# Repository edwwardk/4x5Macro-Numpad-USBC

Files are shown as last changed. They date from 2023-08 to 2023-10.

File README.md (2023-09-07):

## 4x5Macro-Numpad-USBC
This fork of tobychui's 4x5Macro-Numpad modifies the original design to use usbc instead of microusb as well as using a through hole reinforced port for a stronger hold on the board. Additionally, it also moves the user led to the front of the board and adds a button for resetting the mcu. Pins are identical to the 4x5Macro-Numpad to allow for using the same firmwares.

## v1.0 Known Issues
- resistor/capacitor/led designators/value missing from silkscreen in gerbers
- switch indices missing from silkscreen in gerbers
- size is larger than 100x100mm which causes upcharge (at least from jlcpcb)

### Bill of materials
(LCSC manufacturer part numbers in brackets)
- 1x CH552G (CH552G)
- 1x USBC (GT-USB-7010ASV)
- 20x switches for 4x5 layout, 17x switches for numpad layout
- 2x 0.1u 0805 capacitors (0805B104J250CT)
- 2x 0805 LEDs (17-215SURC/S530-A3/4T and BL-HJC35A-AV-TRB)
- 8x 10k 0805 resistors (SCR0805F10K)
- 2x 5.1k 0805 resistors (CR0805J80512G)
- 2x smd momentary buttons (TS5216A 250gf 025)

### Fabrication instructions
- in the "4x5Macro-Numpad-USBC/fabrication" folder there is a zip file called fabrication.zip. these are the set of gerbers required to order from JLCPCB and should work as is.

### Build Instruction

1. Send the PCB to print (See /PCB)

2. Purchase all the required materials (See BOM list)

3. 3D print the base plate (See /3D Model)

4. Install the required Arduino library for CH552G and drivers

5. Visit [4-key Macropad | imuslab](https://tobychui.github.io/4xMacropad/) (4xMacropad only) or modify the sketch in /firmware folder

6. Flash the CH552G with the sketch

### Program Flashing Instructions

As all the keyboard designs share the same MCU and programming button design, this instruction should be suitable for all the macropads / numpad in this repo.

1. Hold and press the PROG button on the PCB

2. While the button has been held, insert the USB cable into the mini USB port

3. Release the button when the Arduino code has finished compiling and ready to upload (Timing is important)

4. Wait for the upload to complete

### License

Software: MIT License

Hardware: CC BY-NC-SA

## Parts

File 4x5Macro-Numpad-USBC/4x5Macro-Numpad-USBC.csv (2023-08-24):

Source: | C:\Users\eddyk\projects\4x5Macro-Numpad-USBC\4x5Macro-Numpad-USBC\4x5Macro-Numpad-USBC.kicad_sch
Date: | 2023-08-22 8:45:27 PM
Tool: | Eeschema 7.0.2
Generator: | C:\Program Files\KiCad\7.0\bin\scripting\plugins/bom_csv_grouped_by_value.py
Component Count: | 41
Collated Components:
Item | Qty | Reference(s) | Value | LibPart | Footprint | Datasheet | DNP
1 | 2 | C1, C2 | 0.1u | Device:C_Small | Capacitor_SMD:C_0805_2012Metric_Pad1.18x1.45mm_HandSolder | ~
2 | 1 | D1 | RED | Device:LED | Capacitor_SMD:C_0805_2012Metric_Pad1.18x1.45mm_HandSolder | ~
3 | 1 | D2 | BLUE | Device:LED | Capacitor_SMD:C_0805_2012Metric_Pad1.18x1.45mm_HandSolder | ~
4 | 1 | J1 | USB-C | Connector:USB_C_Receptacle_USB2.0 | Connector_USB:USB_C_Receptacle_G-Switch_GT-USB-7010ASV | https://www.usb.org/sites/default/files/documents/usb_type-c.zip
5 | 8 | R1, R4, R5, R6, R7, R8, R9, R10 | 10k | Device:R_Small_US | Resistor_SMD:R_0805_2012Metric_Pad1.20x1.40mm_HandSolder | ~
6 | 2 | R2, R3 | 5.1k | Device:R_Small_US | Resistor_SMD:R_0805_2012Metric_Pad1.20x1.40mm_HandSolder | ~
7 | 1 | SW1 | PROG | Switch:SW_Push | custom:SW_SPST_TS5216A | ~
8 | 1 | SW2 | RESET | Switch:SW_Push | custom:SW_SPST_TS5216A | ~
9 | 1 | SW3 | [4,0] | Switch:SW_Push | Button_Switch_Keyboard:SW_Cherry_MX_1.00u_Plate | ~
10 | 1 | SW4 | [4,1] | Switch:SW_Push | Button_Switch_Keyboard:SW_Cherry_MX_1.00u_Plate | ~
11 | 1 | SW5 | [4,2] | Switch:SW_Push | Button_Switch_Keyboard:SW_Cherry_MX_1.00u_Plate | ~
12 | 1 | SW6 | [4,3] | Switch:SW_Push | Button_Switch_Keyboard:SW_Cherry_MX_1.00u_Plate | ~
13 | 2 | SW7, SW11 | [3,3] | Switch:SW_Push | Button_Switch_Keyboard:SW_Cherry_MX_1.00u_Plate | ~
14 | 1 | SW8 | [3,0] | Switch:SW_Push | Button_Switch_Keyboard:SW_Cherry_MX_1.00u_Plate | ~
15 | 1 | SW9 | [3,1] | Switch:SW_Push | Button_Switch_Keyboard:SW_Cherry_MX_1.00u_Plate | ~
16 | 1 | SW10 | [3,2] | Switch:SW_Push | Button_Switch_Keyboard:SW_Cherry_MX_1.00u_Plate | ~
17 | 1 | SW12 | [2,0] | Switch:SW_Push | Button_Switch_Keyboard:SW_Cherry_MX_1.00u_Plate | ~
18 | 1 | SW13 | [2,1] | Switch:SW_Push | Button_Switch_Keyboard:SW_Cherry_MX_1.00u_Plate | ~
19 | 1 | SW14 | [2,2] | Switch:SW_Push | Button_Switch_Keyboard:SW_Cherry_MX_1.00u_Plate | ~
20 | 1 | SW15 | [2,3] | Switch:SW_Push | Button_Switch_Keyboard:SW_Cherry_MX_1.00u_Plate | ~
21 | 2 | SW16, SW20 | [1,3] | Switch:SW_Push | Button_Switch_Keyboard:SW_Cherry_MX_1.00u_Plate | ~
22 | 1 | SW17 | [1,0] | Switch:SW_Push | Button_Switch_Keyboard:SW_Cherry_MX_1.00u_Plate | ~
23 | 1 | SW18 | [1,1] | Switch:SW_Push | Button_Switch_Keyboard:SW_Cherry_MX_1.00u_Plate | ~
24 | 1 | SW19 | [1,2] | Switch:SW_Push | Button_Switch_Keyboard:SW_Cherry_MX_1.00u_Plate | ~
25 | 2 | SW21, SW25 | [0,0] | Switch:SW_Push | Button_Switch_Keyboard:SW_Cherry_MX_1.00u_Plate | ~
26 | 1 | SW22 | [0,1] | Switch:SW_Push | Button_Switch_Keyboard:SW_Cherry_MX_1.00u_Plate | ~
27 | 1 | SW23 | [0,2] | Switch:SW_Push | Button_Switch_Keyboard:SW_Cherry_MX_1.00u_Plate | ~
28 | 1 | SW24 | [0,3] | Switch:SW_Push | Button_Switch_Keyboard:SW_Cherry_MX_1.00u_Plate | ~
29 | 1 | U1 | ~ | custom:CH552G | Package_SO:SOP-16_3.9x9.9mm_P1.27mm

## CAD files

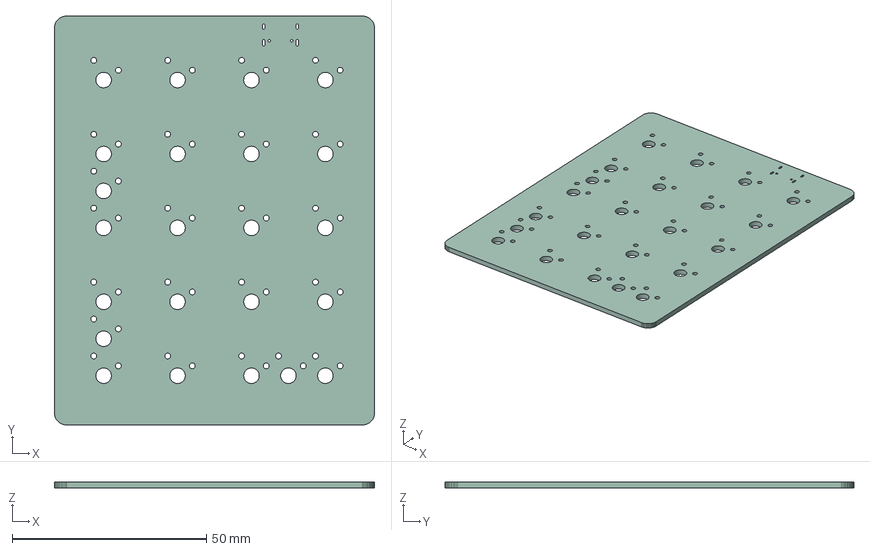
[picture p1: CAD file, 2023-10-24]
4x5Macro-Numpad-USBC/4x5Macro-Numpad-USBC.step
82.5 x 105.4 x 1.58 mm

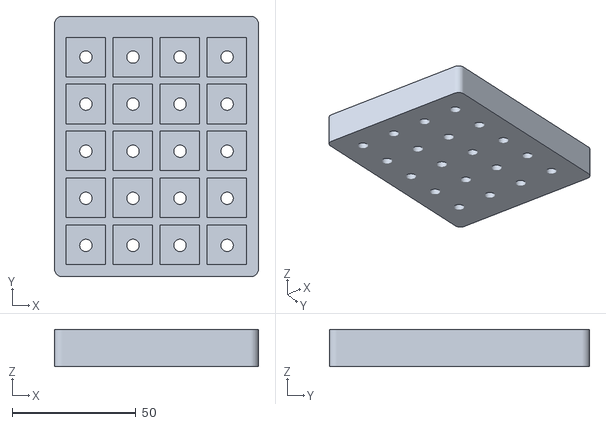
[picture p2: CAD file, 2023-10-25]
4x5Macro-Numpad-USBC/fabrication/macropad-layout-switch-jig.stl
82.5 x 105.4 x 15.0

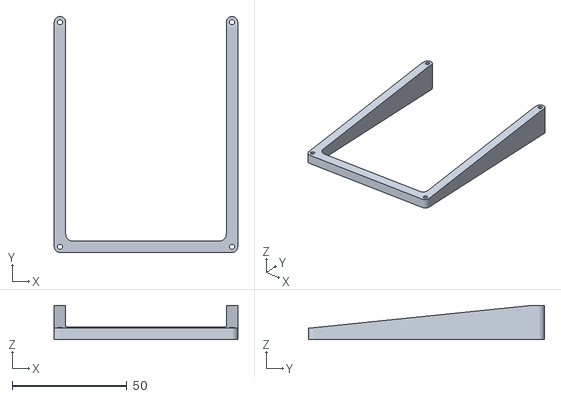
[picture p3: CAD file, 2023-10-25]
4x5Macro-Numpad-USBC/fabrication/thin-base-2.stl
79.9 x 102.8 x 15.0

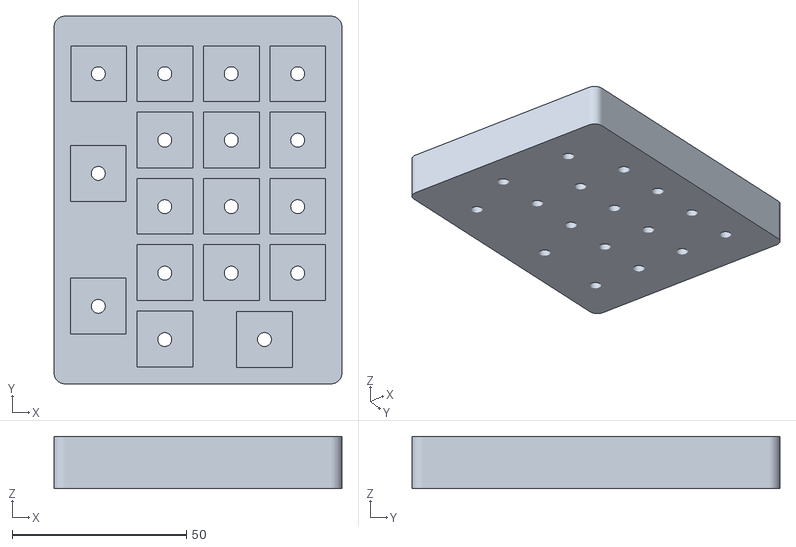
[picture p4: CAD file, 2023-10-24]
4x5Macro-Numpad-USBC/fabrication/numpad-layout-switch-jig.stl
82.5 x 105.4 x 15.0

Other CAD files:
4x5Macro-Numpad-USBC/fabrication/thin-base-1.stl

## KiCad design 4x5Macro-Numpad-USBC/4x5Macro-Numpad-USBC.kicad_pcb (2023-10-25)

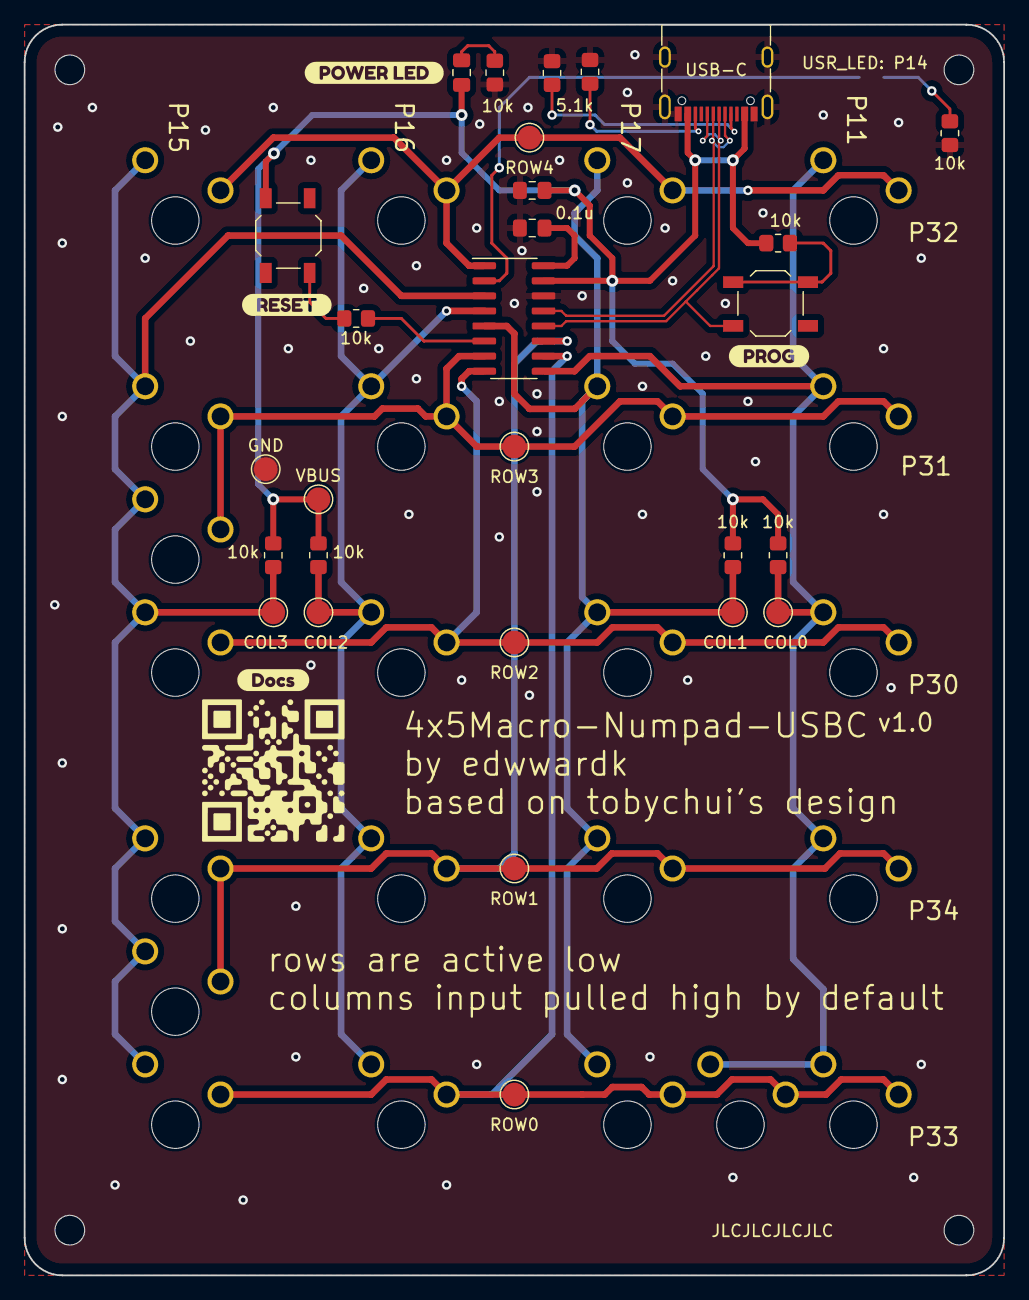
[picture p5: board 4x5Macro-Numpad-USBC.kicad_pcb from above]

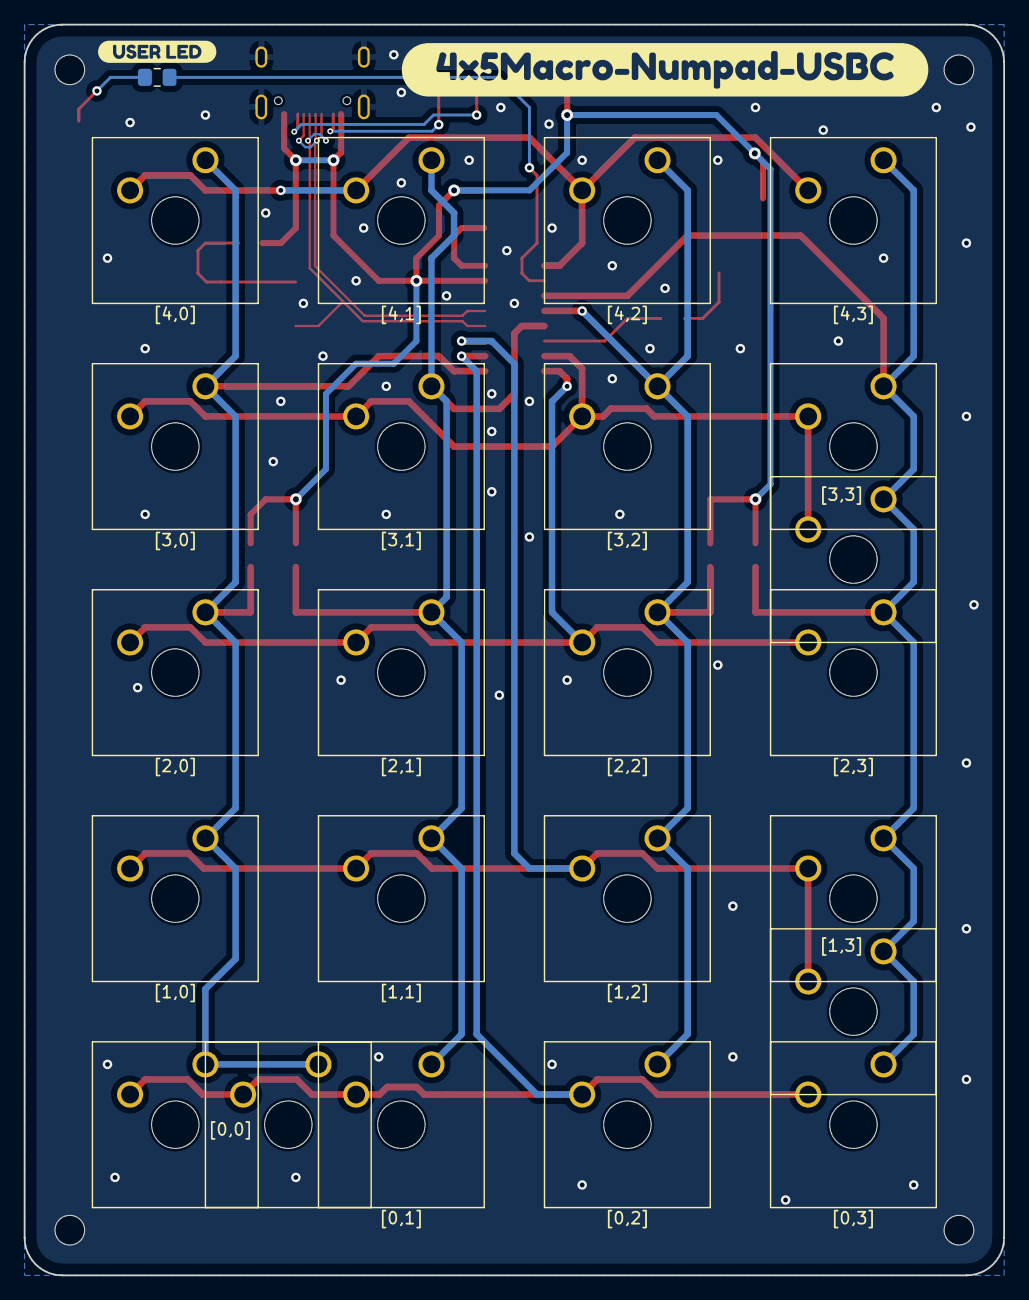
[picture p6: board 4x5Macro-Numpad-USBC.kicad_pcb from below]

Board: 2 copper layers, 82.5 x 105.4 mm, 62 parts (26 on the bottom side), 22 nets.

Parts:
C1, C2: 0.1u; C_0805_2012Metric_Pad1.18x1.45mm_HandSolder
CH1, CH1#2, CH1#3, CH1#4: MountingHole_2.5mm
COL0, COL1, COL2, COL3: TestPoint_Pad_D2.0mm
D1: RED; C_0805_2012Metric_Pad1.18x1.45mm_HandSolder
D2: BLUE; C_0805_2012Metric_Pad1.18x1.45mm_HandSolder
GND: TestPoint_Pad_D2.0mm
J1: USB-C; USB_C_Receptacle_G-Switch_GT-USB-7010ASV
R1, R4, R5, R6, R7, R8, R9, R10: 10k; R_0805_2012Metric_Pad1.20x1.40mm_HandSolder
R2, R3: 5.1k; R_0805_2012Metric_Pad1.20x1.40mm_HandSolder
ROW0, ROW1, ROW2, ROW3, ROW4: TestPoint_Pad_D2.0mm
SW1: PROG; SW_SPST_TS5216A
SW2: RESET; SW_SPST_TS5216A
SW3: [4,0]; SW_Cherry_MX_1.00u_Plate
SW4: [4,1]; SW_Cherry_MX_1.00u_Plate
SW5: [4,2]; SW_Cherry_MX_1.00u_Plate
SW6: [4,3]; SW_Cherry_MX_1.00u_Plate
SW7, SW11: [3,3]; SW_Cherry_MX_1.00u_Plate
SW8: [3,0]; SW_Cherry_MX_1.00u_Plate
SW9: [3,1]; SW_Cherry_MX_1.00u_Plate
SW10: [3,2]; SW_Cherry_MX_1.00u_Plate
SW12: [2,0]; SW_Cherry_MX_1.00u_Plate
SW13: [2,1]; SW_Cherry_MX_1.00u_Plate
SW14: [2,2]; SW_Cherry_MX_1.00u_Plate
SW15: [2,3]; SW_Cherry_MX_1.00u_Plate
SW16, SW20: [1,3]; SW_Cherry_MX_1.00u_Plate
SW17: [1,0]; SW_Cherry_MX_1.00u_Plate
SW18: [1,1]; SW_Cherry_MX_1.00u_Plate
SW19: [1,2]; SW_Cherry_MX_1.00u_Plate
SW21, SW25: [0,0]; SW_Cherry_MX_1.00u_Plate
SW22: [0,1]; SW_Cherry_MX_1.00u_Plate
SW23: [0,2]; SW_Cherry_MX_1.00u_Plate
SW24: [0,3]; SW_Cherry_MX_1.00u_Plate
U1: SOP-16_3.9x9.9mm_P1.27mm
VBUS: TestPoint_Pad_D2.0mm
kibuzzard-64E3BE21: G***; kibuzzard-64E3BE21
kibuzzard-64E3BEC4: G***; kibuzzard-64E3BEC4
kibuzzard-64E425AB: G***; kibuzzard-64E425AB
kibuzzard-64E425E5: G***; kibuzzard-64E425E5
kibuzzard-64E562F3: G***; kibuzzard-64E562F3
kibuzzard-64E42557: G***; kibuzzard-64E42557

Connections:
/USR_LED: D2.2 (A), U1.2 (P1.4)
COL0: COL0.1, R7.1, SW3.1, SW8.1, SW12.1, SW17.1, SW21.1, SW25.1, U1.9 (P1.1)
COL1: COL1.1, R8.1, SW4.1, SW9.1, SW13.1, SW18.1, SW22.1, U1.5 (P1.7)
COL2: COL2.1, R9.1, SW5.1, SW10.1, SW14.1, SW19.1, SW23.1, U1.4 (P1.6)
COL3: COL3.1, R10.1, SW6.1, SW7.1, SW11.1, SW15.1, SW16.1, SW20.1, SW24.1, U1.3 (P1.5)
D+: J1.A6 (D+), J1.B6 (D+), SW1.1, U1.12 (D+/PROG)
D-: J1.A7 (D-), J1.B7 (D-), U1.13 (D-)
GND: C1.1, C2.2, GND.1, J1.A1 (GND), J1.A12 (GND), J1.B1 (GND), J1.B12 (GND), J1.S1 (SHIELD), R2.2, R3.2, R4.2, R6.2, U1.14 (VSS)
unnamed: D1.1 (K), R4.1
unnamed: D2.1 (K), R6.1
unnamed: J1.A5 (CC1), R2.1
unnamed: J1.B5 (CC2), R3.1
unnamed: R1.1, SW1.2
unnamed: R5.1, SW2.2
unnamed: C1.2, U1.16 (CAP)
unnamed: R5.2, U1.6 (RST)
ROW0: ROW0.1, SW21.2, SW22.2, SW23.2, SW24.2, SW25.2, U1.10 (P3.3)
ROW1: ROW1.1, SW16.2, SW17.2, SW18.2, SW19.2, SW20.2, U1.11 (P3.4)
ROW2: ROW2.1, SW12.2, SW13.2, SW14.2, SW15.2, U1.8 (P3.0)
ROW3: ROW3.1, SW7.2, SW8.2, SW9.2, SW10.2, SW11.2, U1.7 (P3.1)
ROW4: ROW4.1, SW3.2, SW4.2, SW5.2, SW6.2, U1.1 (P3.2)
VBUS: C2.1, D1.2 (A), J1.A4 (VBUS), J1.A9 (VBUS), J1.B4 (VBUS), J1.B9 (VBUS), R1.2, R7.2, R8.2, R9.2, R10.2, SW2.1, U1.15 (VDD), VBUS.1

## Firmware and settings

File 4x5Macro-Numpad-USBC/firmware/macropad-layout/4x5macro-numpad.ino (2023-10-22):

/*
    4x5 Macropad

    if you are using the Numpad arrangement, use the numpad firmware
*/
#ifndef USER_USB_RAM
#error "Require USB RAM. Go Tools > USB Setting and pick the 2nd option in the dropdown list"
#endif

#include "src/userUsbHidMediaKeyboard/USBHIDMediaKeyboard.h"

////////////// HARDWARE CONFIG //////////
//LED OUTPUT
#define LED_OUT 14


//SCAN LINES
//Input Pins. Pull High (When reading is low = pressed)
#define COL_1 15
#define COL_2 16
#define COL_3 17
#define COL_4 11

//Output Pins. Set to low to scan that line
#define ROW_1 32
#define ROW_2 31
#define ROW_3 30
#define ROW_4 34
#define ROW_5 33

///////////////// RUNTIME ///////////////
const int readColSeq[4] = {COL_4, COL_3, COL_2, COL_1};
const int scanRowSeq[5] = {ROW_5, ROW_4, ROW_3, ROW_2, ROW_1};
bool funcMode = false; //If Fn key is hold (Default func key: [0,1]

//The layout is identical to the keypad when view from the front side (i.e. not the MCU side)
int keyPressState[5][4] = {
  {false,false,false,false},
  {false,false,false,false},
  {false,false,false,false},
  {false,false,false,false},
  {false,false,false,false},
};

///////////////// FUNC PROTOTYPES ///////////////
void HandleKeyPressEvents(int row, int col, bool previousState, bool currentState);
void PressNumericAsKeypad(char in);
void UpdateLEDState();


void setup() {
  delay(300);
  USBInit();
  //LED
  pinMode(LED_OUT, OUTPUT);

  //Sensing lines
  pinMode(COL_1, INPUT);
  pinMode(COL_2, INPUT);
  pinMode(COL_3, INPUT);
  pinMode(COL_4, INPUT);

  //Select lines
  pinMode(ROW_1, OUTPUT);
  pinMode(ROW_2, OUTPUT);
  pinMode(ROW_3, OUTPUT);
  pinMode(ROW_4, OUTPUT);
  pinMode(ROW_5, OUTPUT);

  //Set all lines to high (active low)
  digitalWrite(ROW_1, HIGH);
  digitalWrite(ROW_2, HIGH);
  digitalWrite(ROW_3, HIGH);
  digitalWrite(ROW_4, HIGH);
  digitalWrite(ROW_5, HIGH);
}

//Activate the row to be scanned
void setScanningRow(int rowNumber) {
  //Hardcoding the sequence save some RAM and faster :)
  (rowNumber==0)?digitalWrite(scanRowSeq[0], LOW):digitalWrite(scanRowSeq[0], HIGH);
  (rowNumber==1)?digitalWrite(scanRowSeq[1], LOW):digitalWrite(scanRowSeq[1], HIGH);
  (rowNumber==2)?digitalWrite(scanRowSeq[2], LOW):digitalWrite(scanRowSeq[2], HIGH);
  (rowNumber==3)?digitalWrite(scanRowSeq[3], LOW):digitalWrite(scanRowSeq[3], HIGH);
  (rowNumber==4)?digitalWrite(scanRowSeq[4], LOW):digitalWrite(scanRowSeq[4], HIGH);
  
  //Disable all and enable the target one not sure why it is not working
  
  //Activate the target row
  //int targetRowPin = scanRowSeq[rowNumber];
  //digitalWrite(targetRowPin, LOW);
  //delay(50);  //naive debouncing
}

//Read and return the key press status of a given column
//Notes: keys are low activated. When not press, the keys are pull HIGH
bool readKeyPress(int colNumber){
  int readPin = readColSeq[colNumber];
  return (digitalRead(readPin) == 0);
}


//Read all the switches states and update to the global array
void updateSwitchStatus() {
  for (int i = 0; i < 5; i++) {
    //For each of the row, read each of the col switch
    setScanningRow(i);
    for (int j = 0; j < 4; j++) {
      bool isKeyDown = readKeyPress(j);
      bool prevState = keyPressState[i][j];
      if (isKeyDown != prevState){
        //Trigger on change events
        
        HandleKeyPressEvents(i,j,prevState,isKeyDown);
        delay(10); //resp time
      }
      keyPressState[i][j] = isKeyDown;
    }
  }
}

//Update the LED status
void UpdateLEDState(){
  if (funcMode) {
    digitalWrite(LED_OUT, HIGH);
  } else {
    digitalWrite(LED_OUT, LOW);
  }
}

void loop() {
  //Read the mode of the keyboard
  updateSwitchStatus();
  
  //Update the NumLock LED
  UpdateLEDState();
}

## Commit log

2023-08-21 sch done, footprints in, switches arranged
    [4x5Macro-Numpad-USBC.kicad_pcb, 4x5Macro-Numpad-USBC.kicad_sch]
2023-08-22 fin+check sch, route pcb, silkscreen todo
    [4x5Macro-Numpad-USBC.kicad_pcb]
2023-08-23 mask done, first board revision
    [4x5Macro-Numpad-USBC-B_Cu.gbl, 4x5Macro-Numpad-USBC-B_Mask.gbs, 4x5Macro-Numpad-USBC-B_Paste.gbp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]
2023-08-24 board vers 1.0
    [4x5Macro-Numpad-USBC.csv, 4x5Macro-Numpad-USBC.kicad_pcb]
2023-10-24 start cad files
    [4x5Macro-Numpad-USBC.kicad_pcb, 4x5Macro-Numpad-USBC.step, numpad-layout-switch-jig.stl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]
2023-10-25 basic case, mounting holes fixed, 3d models
    [4x5Macro-Numpad-USBC.kicad_pcb, macropad-layout-switch-jig.stl, thin-base-2.stl]
